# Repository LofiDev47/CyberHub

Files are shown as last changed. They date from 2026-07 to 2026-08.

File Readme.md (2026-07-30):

## CyberHub 
the cyberpunk (kinda) themed USB hub

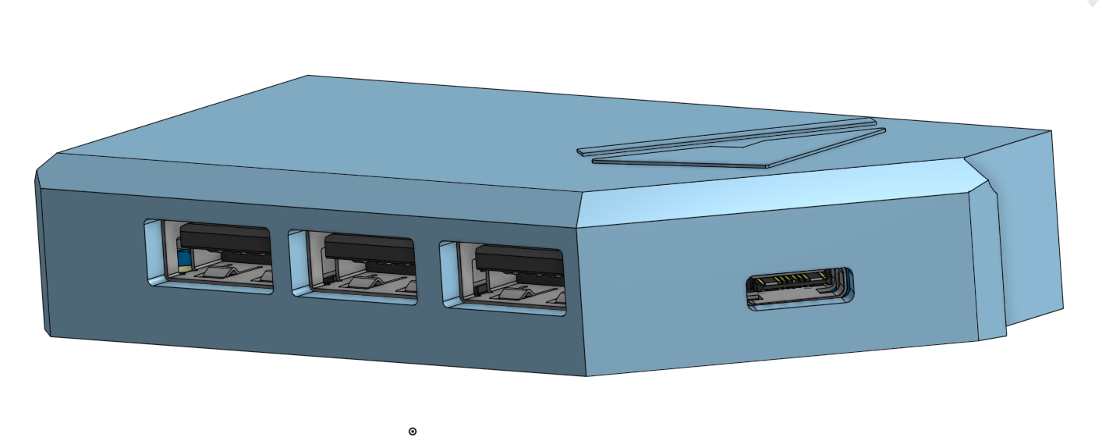
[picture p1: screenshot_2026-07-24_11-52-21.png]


It has 5 USB ports 
with 1 type-c to connect to the computer
and 3 USB-a and 1 USB-c for the peripherals
all being drive by the CoreChips SL2.1s Usb 2 chip

heres the link to the onshape project for those interested
https://cad.onshape.com/documents/5a75bb55e0aecf78693a2579/w/da3bd1f2543066ad8ce58978/e/36d5b5ca91d48c9aa82f422e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

oshwlab 
 https://oshwlab.com/thedragonrider46/project_qsftfapj

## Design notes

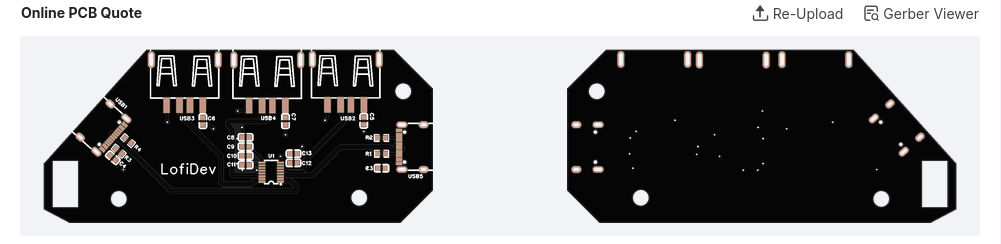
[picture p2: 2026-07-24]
screenshot_2026-07-24_11-59-00.png

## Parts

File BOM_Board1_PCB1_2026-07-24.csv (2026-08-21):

No. | Quantity | Comment | Designator | Footprint | Value | Manufacturer Part | Manufacturer | Supplier Part | Supplier | JLCPCB Stock | JLCPCB Price | Link
1 | 8 | 1uF | C3,C4,C5,C6,C7,C8,C10,C12 | C0603 | 1uF
2 | 3 | 100nF | C9,C11,C13 | C0603 | 100nF
3 | 4 | 5.1k | R1,R2,R3,R4 | R0603 | 5.1k
4 | 1 | SL2.1s | U1 | SSOP-16_L4.6-W2.6-P0.53-LS4.0-BL |  | SL2.1s | CoreChips(和芯润德) | C2684433 | LCSC | 14997 | 0.0374 | jlcpcb.com/partdetail/CoreChips-SL21s/C2684433
5 | 2 | TYPE-C 16PIN 2MD(073) | USB1,USB5 | USB-C-SMD_TYPE-C-16PIN-2MD-073 |  | TYPE-C 16PIN 2MD(073) | SHOU HAN(首韩) | C2765186 | LCSC | 1108047 | 0.011 | https://www.lcsc.com/product-detail/C2765186.html
6 | 3 | 10.0 QHHTZB6.3 | USB2,USB3,USB4 | USB-A-TH_10.0QHHTZB6.3 |  | 10.0 QHHTZB6.3 | SHOU HAN(首韩) | C668591 | LCSC | 40687 | 0.0099 | https://www.lcsc.com/product-detail/C668591.html

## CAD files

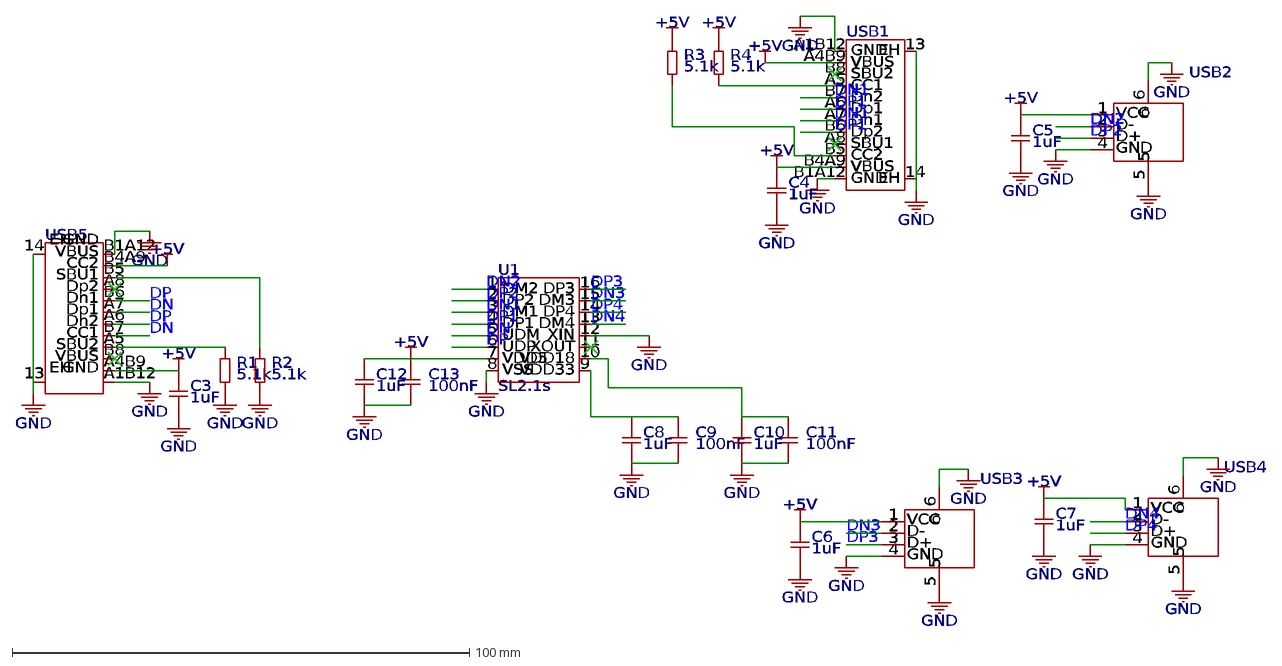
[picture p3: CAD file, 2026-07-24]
CyberHubWiringDiagram.dxf
U1
SL2.1s
DM2
1
DP2
2
DM1
3
DP1
4
UDM
5
UDP
6
VDD5
7
VSS
8
VDD33
9
VDD18
10
XOUT
11
XIN
12
DM4
13
DP4
14
DM3
15
DP3
16
USB1
GND
A1B12
VBUS
A4B9
SBU2
B8
CC1
A5
Dn2
B7
Dp1
A6
Dn1
A7
Dp2
B6
SBU1
A8
CC2
B5
B4A9
B1A12
EH
USB2
D+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

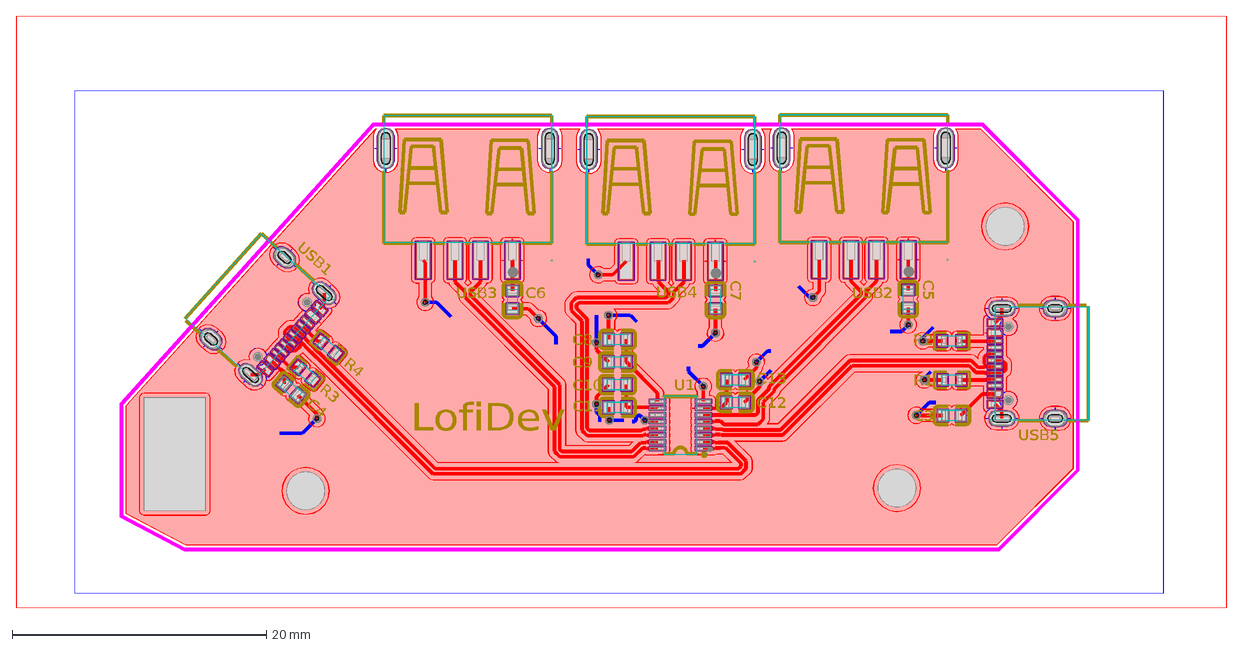
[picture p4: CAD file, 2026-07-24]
CyberHubPCB.dxf
LofiDev
C3
C4
C5
C6
C7
C8
C9
C10
C11
C12
C13
R1
R2
R3
R4
U1
USB1
USB2
USB3
USB4
USB5

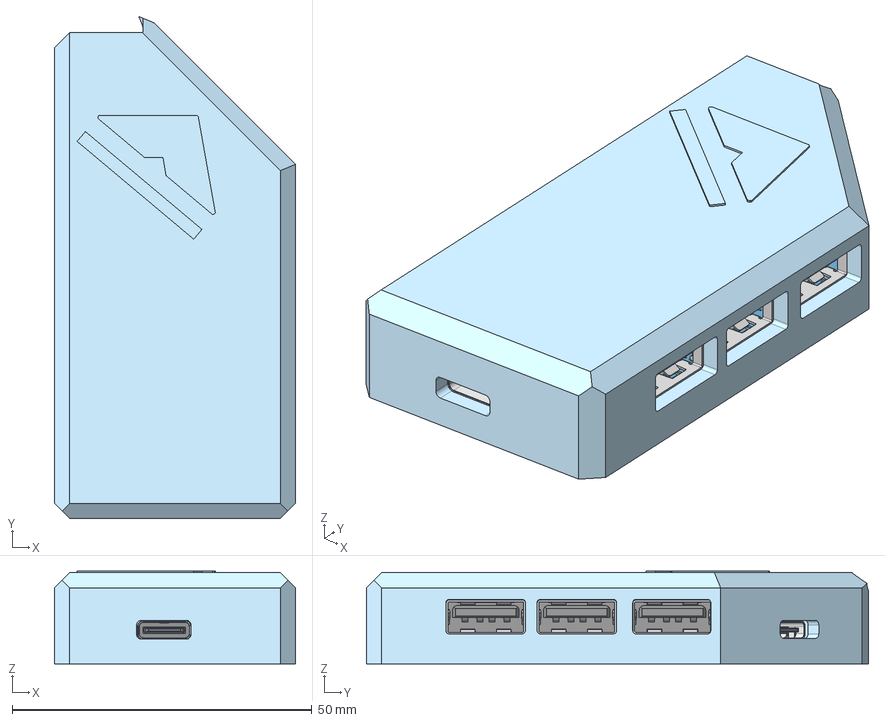
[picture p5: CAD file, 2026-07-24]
USB hub case model.step
40.2 x 83.7 x 15.5 mm
TopSilkscreen~BaCn x 132
C0603~C0603_L1.6-W0.8-H0.8~BaCn x 11
Board~BaCn
R0603~R0603~BaCn x 16
SSOP-16_L4.6-W2.6-P0.53-LS4.0-BL~SSOP-16_L4.6-W2.6-P0.53-LS4.0-BL~BaC n x 14
USB-A-TH_10.0QHHTZB6.3~USB-A-TH_10.0QHHTZB6.3~BaCn x 30
USB-C-SMD_TYPE-C-16PIN-2MD-073~USB-C-SMD_HYCW498-USBC16-735B~BaCn x 56

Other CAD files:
CyberHubSchematic.dxf
USB hub model.stl

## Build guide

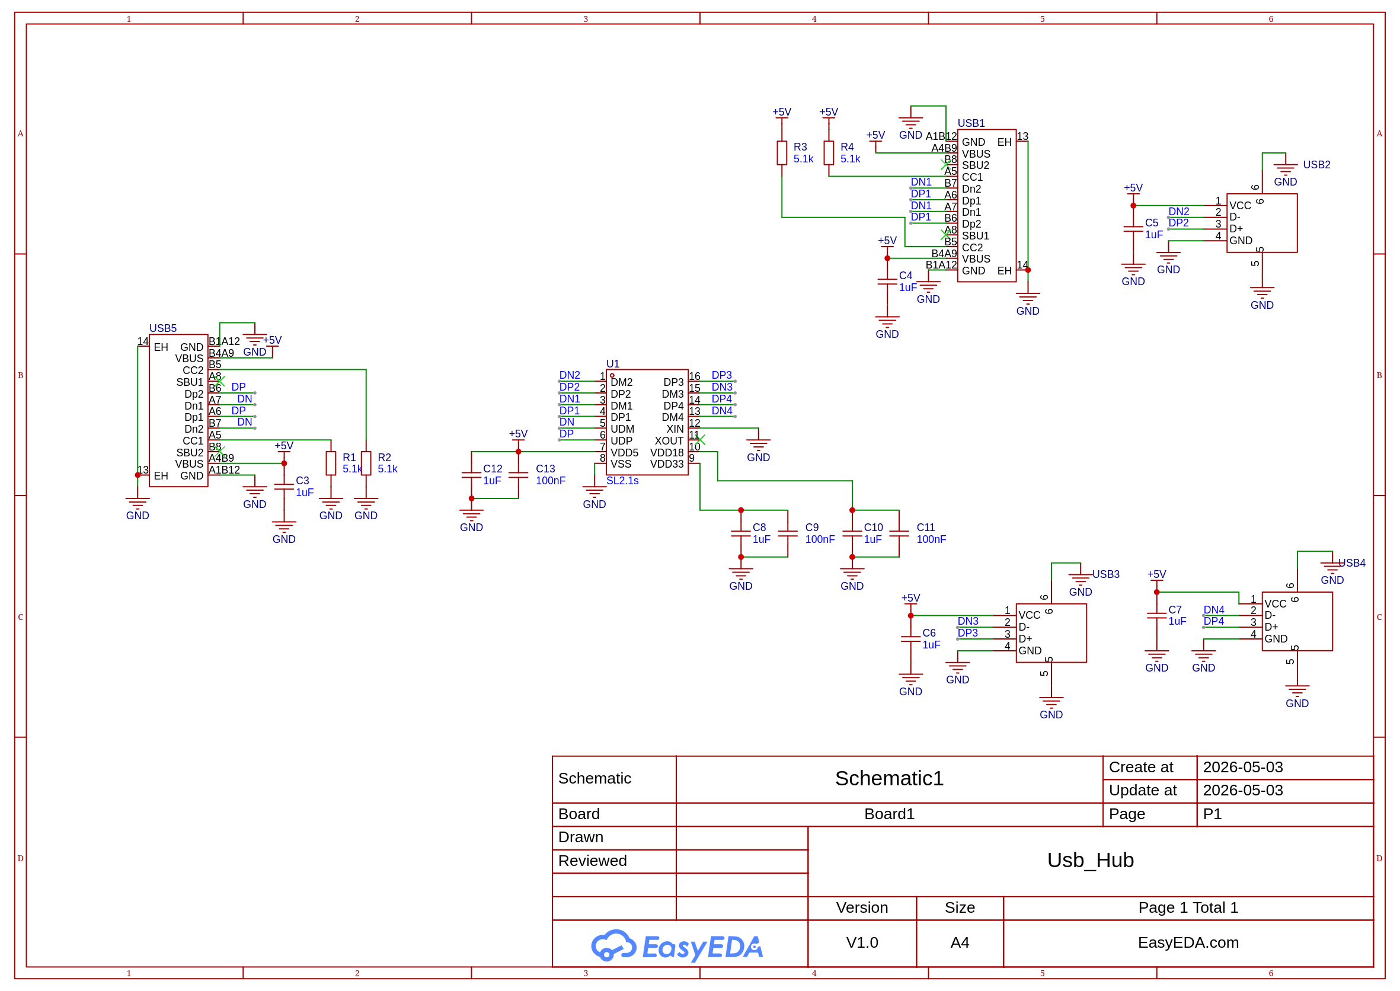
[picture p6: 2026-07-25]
wiring diagram.png

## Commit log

2026-05-29 Create Complete modelmm.stl
    [Complete modelmm.stl]
2026-07-24 Add CyberHubWiringDiagram.dxf file
    [CyberHubWiringDiagram.dxf]
2026-07-25 Rename SCH_Schematic1_1-P1_2026-07-24.png to wiring diagram.png
2026-07-30 remove stale stl
    [Complete modelmm.stl]
2026-07-30 Added Gerber file
2026-08-21 Add component links to BOM
    Added links for components in the BOM.
    [BOM_Board1_PCB1_2026-07-24.csv]
